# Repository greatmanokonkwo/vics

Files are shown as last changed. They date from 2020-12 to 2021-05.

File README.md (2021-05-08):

# V.I.C.S (Visual Impairment Companion System)
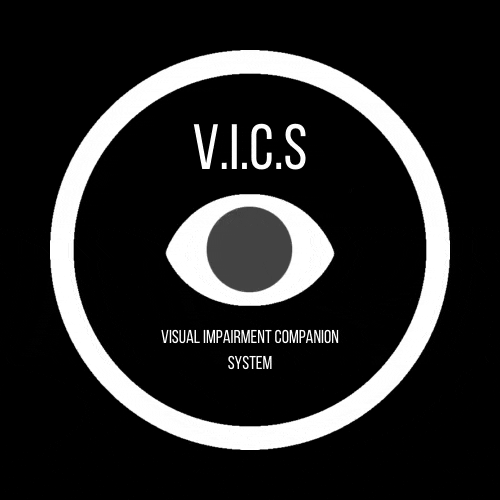
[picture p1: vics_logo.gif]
VICS LOGO

 
**Powered by Nvidia**

VICS is an end-to-end learning based visual impairment device that strives to make the world more accessible to the visually impaired. VICS is currently made up of three separate systems that work to bring the world to the user via a suite of information rallying devices including vibration motors and speech enabled assistance.

## Running on native machine
### Hardware Configuration
```
sudo /opt/nvidia/jetson-io/jetson-io.py (Configure mic hardware first then configure i2s4 pins)
sudo grep dap4 /sys/kernel/debug/tegra_pinctrl_reg
alsactl init tegrasndt210ref
amixer -c tegrasndt210ref cset name="MVC1 Mux" I2S4
amixer -c tegrasndt210ref cset name="ADMAIF1 Mux" MVC1
amixer -c tegrasndt210ref cset name="MVC1 Vol" 13500
amixer -c tegrasndt210ref cset name='I2S4 codec bit format' 32
amixer -c tegrasndt210ref sget "MVC1 Channels"
````

### Pytorch prerequisites
```
sudo apt-get install -y --no-install-recommends python3-pip python3-dev libopenblas-dev libopenmpi2 openmpi-bin openmpi-common gfortran && sudo rm -rf /var/lib/apt/lists/*
pip3 install setuptools Cython wheel
pip3 install numpy --verbose
```
### Pytorch for Jetson nano

*Instructions from https://forums.developer.nvidia.com/t/pytorch-for-jetson-version-1-7-0-now-available/72048*

Install PyTorch pip wheel v1.8.0

```
wget https://nvidia.box.com/shared/static/p57jwntv436lfrd78inwl7iml6p13fzh.whl -O torch-1.8.0-cp36-cp36m-linux_aarch64.whl
sudo apt-get install python3-pip libopenblas-base libopenmpi-dev 
pip3 install Cython
pip3 install numpy torch-1.8.0-cp36-cp36m-linux_aarch64.whl
```
Install torchvision
```
sudo apt-get install libjpeg-dev zlib1g-dev libpython3-dev libavcodec-dev libavformat-dev libswscale-dev
git clone --branch v0.9.0 https://github.com/pytorch/vision torchvision   # see below for version of torchvision to download
cd torchvision
export BUILD_VERSION=0.9.0
sudo python3 setup.py install    
cd ../ 
```
Install torchaudio
```
sudo apt-get update 
sudo apt-get install sox libsox-dev libsox-fmt-all
git clone -b v0.8.0 https://github.com/pytorch/audio torchaudio
cd torchaudio
export BUILD_VERSION=0.8.0
sudo python3 setup.py install
```

### pip install packages
```
sudo apt-get install portaudio19-dev
pip3 install --user --upgrade -r requirements.txt
```

### Google Cloud Text-to-Speech API key

```
wget https://dl.google.com/dl/cloudsdk/channels/rapid/downloads/google-cloud-sdk-329.0.0-linux-x86_64.tar.gz
tar -xvzf google-cloud-sdk-329.0.0-linux-x86_64.tar.gz
./google-cloud-sdk/install.sh
(Select mystical-ace-305717 project)
./google-cloud-sdk/bin/gcloud init
source ~/.bashrc
gcloud auth list
gcloud config list project
gcloud services enable texttospeech.googleapis.com
export PROJECT_ID=$(gcloud config get-value core/project)
echo "export PROJECT_ID=$(gcloud config get-value core/project)" > ~/.bashrc
gcloud iam service-accounts keys create ~/key.json --iam-account my-tts-sa@${PROJECT_ID}.iam.gserviceaccount.com
export GOOGLE_APPLICATION_CREDENTIALS=~/key.json
echo export GOOGLE_APPLICATION_CREDENTIALS=~/key.json > ~/.bashrc
```

### Google Tesseract-OCR Engine
```
sudo apt get install tesseract-ocr
sudo apt-get install libjpeg8 libjpeg62-dev libfreetype6 libfreetype6-dev
wget https://github.com/ZER-0-NE/EAST-Detector-for-text-detection-using-OpenCV/blob/master/frozen_east_text_detection.pb
```

### YOLOV3 weights file

Download the weights file in ``vics/speech_and_comms/scene_describe_system/weights``

```
wget https://pjreddie.com/media/files/yolov3-tiny.weights
```
## TO-DO 
**NOTE:** All tasks involving the GPS Guidance System should be held off until everything else has been completed. This is only an extension of the project.

### General Hardware

- [x] Jetson Nano Developer Kit 4-GB
- [ ] Design rechargeable battery / buy a rechargeable battery

### 1. Direction Planning System

#### Software 

- [x] Implement AlexNet architecture for Direction Planning (direction_plan/neuralnet/model.py) 
- [x] Write training process for the Direction Planning System (direction_plan/neuralnet/train.py)
- [x] Interface vibration motor for halt signalling (direction_plan/devices/vibrator_motor.py)
- [x] Finish up mpu6050 code to enable calculation of Yaw angle (direction_plan/devices/mpu6050.py)
- [x] Figure out halt signal calculations (direction_plan/collect_data.py)
- [x] Build direction_plan interfacing engine (direction_plan/engine.py)
- [ ] Collect data (data such as stopping at cross walks and roads be very helpful)

#### Hardware

- [x] MPU9250 9-axis IMU sensor
- [x] Raspberry Pi Camerasudo apt-get install libjpeg8 libjpeg62-dev libfreetype6 libfreetype6-dev
- [x] 2x Vibration motors
- [x] Get and setup Macro/Wide lens for Pi Camera

### 2. Speech and Communications Systems (Voice Assistant and Scene Description)

#### Sofware

- [x] Interface with microphone hardware
- [x] Interface with speaker hardware
- [x] Write object detection model 
- [x] Build WakeWord model for AI voice assistant (wake word: "Hey VICS")
- [x] Build NLP model for taking in audio input and return a classification for the command issued
- [x] Using the detected objects find way to create voice responses with the detected objects
- [x] Write data collection scripts

#### Hardware

- [x] SPH0645LM4H MEMS Microphone
- [x] MAX98357A Amflifier

### Product Design

#### Software

- [x] Design CAD for Enclosure using FreeCAD

#### Hardware

- [x] Create chest mount straps
- [x] 3d print Enclosure

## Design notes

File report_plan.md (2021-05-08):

# VICS (Visual Impairment Companion System) Technical Report

## Introduction
- The challenges faced by visually impaired
- WHO fact
- Personal Motivation
- Objective of project

## Research & Investigations

### Navigation
- Initial considerations and wants
- Investigated methods and their advantages and disadvantages
- Current method in-depth description, advantages and disadavantages

### Object Detection
- Talk about YoloV3 detection accuracy and speed

### Reading
- Talk about EAST detection
- Talk about Tesseract OCR 

## Hardware System Overview
- Sensors and hardware, used and why
- Circuit Diagram

## Software System Architecture

### Navigation
- System implemenation (system design) (See fig. 2 of main paper)

### Figures
- Create software architecture figure (See fig. 2 of main paper)
- Create logic flowchart of software system

## Training
- Talk about how Yolo, east, & tesseract are pretrained modules
- Briefly explaining training to the layman
- Talk about hardware used for training

### Navigation 
- Talk about data collection methods, as well as some of the data collected
- Talk about loss functions, training accuracies
- Show graph of training

### Wakeword module
- Talk about data collection methods and technques
- Talk about model accuracies
- Show graph for training

### Commands module
- Talk about data collection methods and techniques
- Talk about model accuracies
- Show graph for training

## Results

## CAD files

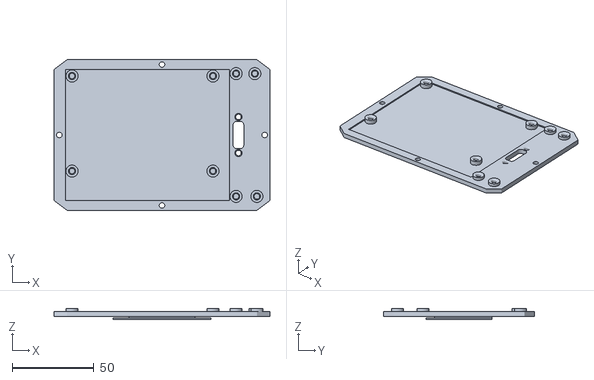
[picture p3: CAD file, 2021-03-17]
hardware/vics_bottom.stl
131.8 x 92.0 x 7.00

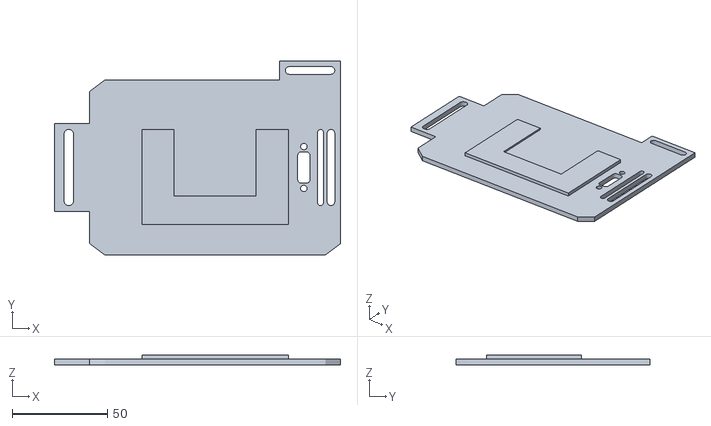
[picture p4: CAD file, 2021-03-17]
hardware/chest_mount.stl
150.3 x 102.0 x 5.00

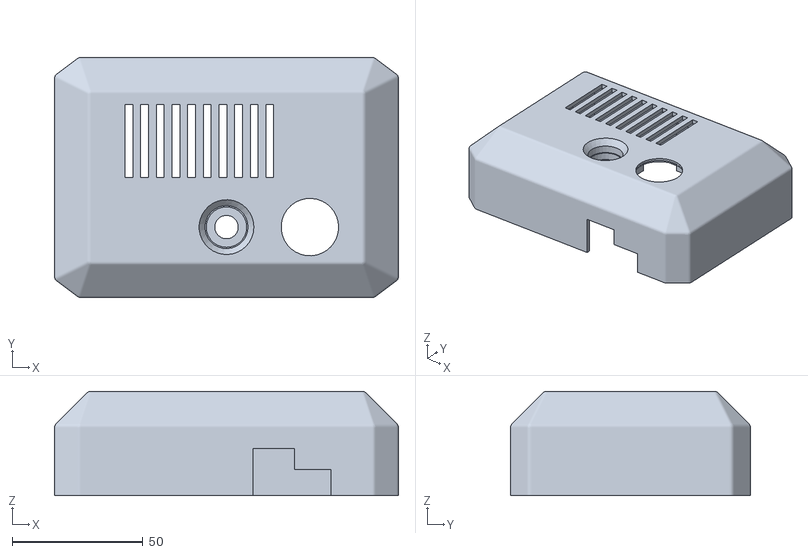
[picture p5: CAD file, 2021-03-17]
hardware/vics_top.stl
131.8 x 92.0 x 40.0

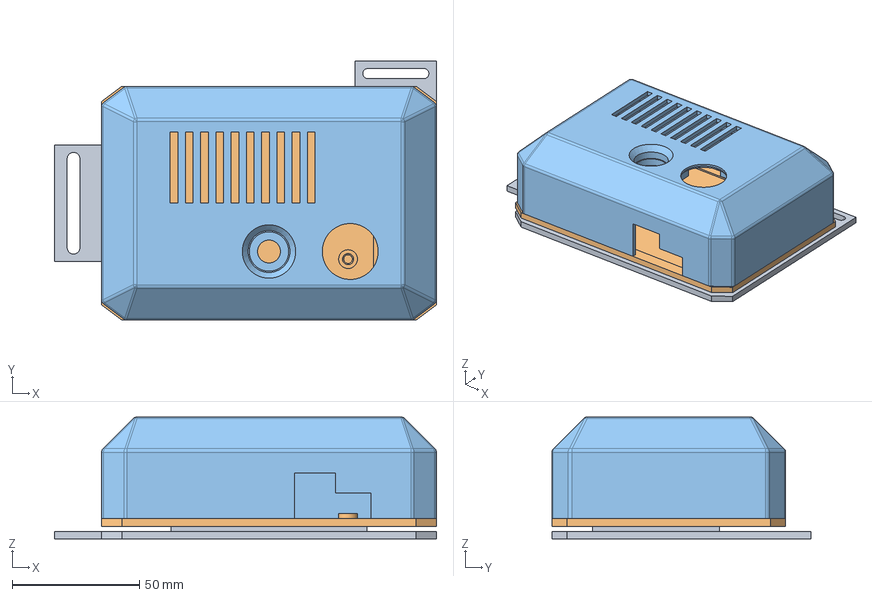
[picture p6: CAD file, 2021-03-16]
hardware/VICS_PARTS_CAD.FCStd
150.3 x 102.0 x 48.0 mm
Chest Mount
Bottom
Top

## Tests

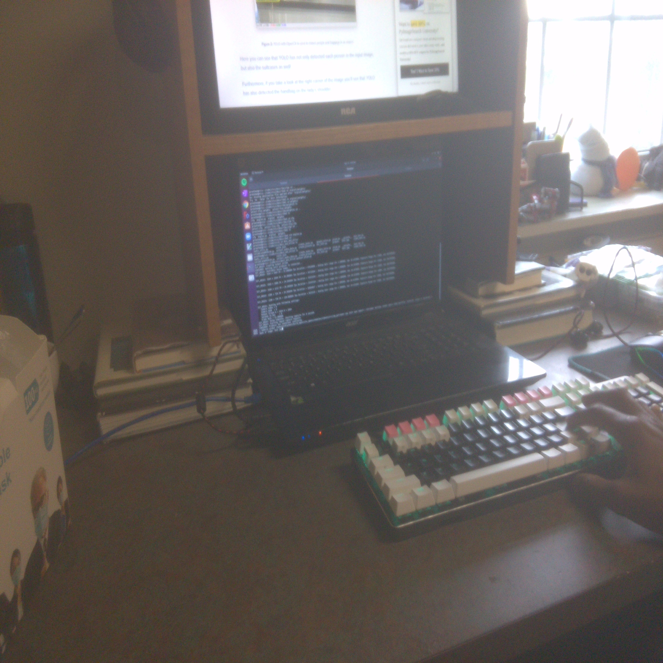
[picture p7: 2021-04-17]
describe/imgs/test.jpg

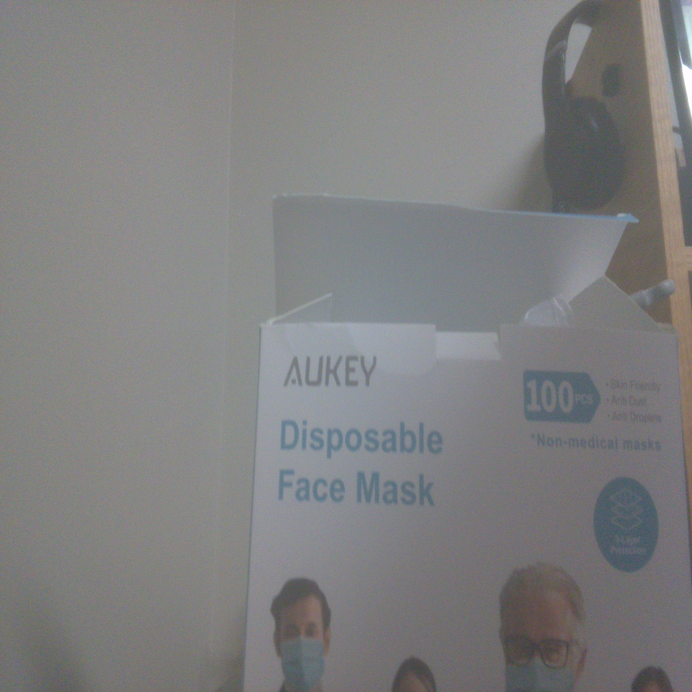
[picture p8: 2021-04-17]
read/test.jpg

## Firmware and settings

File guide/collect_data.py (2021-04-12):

"""
BEFORE RUNNING DATA_COLLECTION SCRIPT MAKE SURE THE MPU9250 HAS BEEN PROPERLY CALIBERATED AND PRODUCEDS ACCURATE YAW VALUES

SPEED CONSIDERATIONS:
- Walk at an average pace of 0.5 m/s or anything around there. 
- If you need to walker faster/slower then you would need to change to update time of the collector
- The collector runs at an update time of approx 1 second (collects image and direction pairs)
- Modify the UPDATE_TIME constant just on the top of the file. The wearter can test out direction UPDATE_TIME values for optimal usage

ROTATIONS:
- Rotations are calculated as the maximum displacement angle within the UPDATE_TIME span
- That being said the wearer should be certain of the direction they want to go. Make dilberate turns
- DON'T TURN MORE THAN 90 DEGREES IN EACH DIRECTION! The system only considers angles within [-101.25, 101.25] degrees (202.25 degrees) 
- Rotations should also be done in the window of the update time 

STOPPING:
- The stopping detector works by keep track of the bouncing motion on the z-axis. 
- Since while walking the user moves up and down and algorithm knows the user has stopped walking when the up and down motion stops
- The up and down motion is detected using the accelerometer sensors z-axis
- At rest the value of the accelerometer's z-axis is -9.8 meters, representing the acceleration due to gravity
- The algorithm calculates the accelerometer values over the spand of UPDATE_TIME and saves the maximum value over that interval
- Then, if the difference betwee n the maximum acceleration value and the rest value is greater than some threshold value THRESH, it is concluding that user is walking
- The value of THRESH can be tweaked to match the walking style of the user.

TESTING:
- For testing the angle, halt and final direction class values are printed out to the standard output
- Looking at these values can help tweak some of the values like UPDATE_TIME and THRESH
- For more testing on the mpu9250 yaw estimation and halt detection, go to ../devices/test_mpu.py

STOPPING CONDITIONS:
- Stop when a human being is in front of you
- Stop in front of a crosswalk
- Stop when there is a closed door in front of you in a closed room, open in the door and continue. Whiling opeing door, try not to make a lot of movements
- Stop when stairs have been encountered. Try to get top and bottom views of stairs in data. Same goes for escalators if any encountered. Highly doubt though

WHAT TO DO:
- Walk down multiple routes like you would normally do
- Try to capture edge cases such as environments with glass doors, stairs, and crosswalks from direction viewing angles, while walking
""" 

import os
os.sys.path.append("..")

import cv2
import time
import smbus

from imusensor.MPU9250 import MPU9250
from imusensor.filters import madgwick

from devs_and_utils.picam import picam 

# UPDATE TIMER VARAIBLE
UPDATE_TIME = 2.8
MIDLINE = -9.8
THRESH = 0.6

# MPU9250 IMU sensor and sensorfusion algorithm
sensorfusion = madgwick.Madgwick()
imu = None 

# Raspberry Pi Camera V2
cam = None 

capture_type = None # The script can either collect image data from live camera feed or prerecorded and saved video data

initial_yaw = 0

def initialize_devices(width=256, height=256):
	global imu

	if capture_type == "live":
		global cam 
		cam = picam(width, height)
	
	# Initialize MPU-6050 device
	address = 0x68
	bus = smbus.SMBus(1)
	imu = MPU9250.MPU9250(bus, address)
	imu.begin()
	
	calib_file = "../devs_and_utils/calib.json" # path of caliberation file with caliberated values

	if os.path.exists(calib_file):	
		imu.loadCalibDataFromFile(calib_file)
	else:
		print("Unable to find IMU caliberation file")

# Classify a given angle in degrees as one of the 9 direction classes
# [-PI/2, -3PI/8, -PI/4, -PI/8, 0, PI/8, PI/4, 3PI/8, PI/2]
def get_direction_class(angle):
	if (angle < -67.5) & (angle >= -112.5):
		return 0
	elif (angle < -22.5) & (angle >= -67.5):
		return 1
	elif (angle < 22.5) & (angle >= -22.5):
		return 2
	elif (angle < 67.5) & (angle >= 22.5):
		return 3
	elif (angle < 112.5) & (angle >= 67.5):
		return 4
	else:
		return -1
		
def calculate_yaw(currTime):
	
	# Calculate the change in the yaw angle of the mpu9250 device
	for i in range(10):
		newTime = time.time()
		dt = newTime - currTime
		currTime = newTime

		sensorfusion.updateRollPitchYaw(imu.AccelVals[0], imu.AccelVals[1], imu.AccelVals[2], imu.GyroVals[0], imu.GyroVals[1], imu.GyroVals[2], imu.MagVals[0], imu.MagVals[1], imu.MagVals[2], dt)
	
	return currTime

# Data collection process	
def data_collection(mins, path, fps, sample):
	global prevTime_yaw, prevTime_vel

	# Creating a VideoCapture object to read the video
	cap = cv2.VideoCapture(sample)

	# Get the ID of the last processed data sample
	with open(path+"/last.txt") as f:
		count = int(f.read())

	START_TIME = time.time()	

	img = None

	# Yaw calculation variables
	prev_yaw = 0
	direct_class = None
	max_angle = 0
	initial_yaw = 0

	# Halt classification variables
	## Halting is classified by using the principle that when people walk they oscillate up and down. Given the acceleration in the z-axis we can thus determine if the user is walking by calculating the amplitude value at a given interval. If the amplitude is below a certain threshold that means the user is not walking
	midline = -9.8
	thresh = 0.6
	max_accel = -999	

	currTime = time.time()

	# Loop until specified minutes have elasped

	if capture_type == "live":
		
		interval_start = START_TIME
		new_interval = True

		while time.time() - START_TIME < mins*60:

			imu.readSensor()
			currTime = calculate_yaw(currTime)

			newTime = time.time()

			# The sensor fusion algorithm spends the first few seconds of calculations slightly off. In order not the take this off values as are starting values we retake the initial_yaw for the first five seconds
			if newTime - START_TIME < 12.5:
				initial_yaw = sensorfusion.yaw
				interval_start = newTime
				continue
			
			# Take a frame from each second of the video
			if new_interval:
				new_interval = False
				img = cam.capture_image()
				
			# Calculate maximum accelorometer value on the z-axis
			max_accel = max(imu.AccelVals[2], max_accel)

			yaw_angle = -(sensorfusion.yaw - initial_yaw) # The magnetometer measures heading from the earth's true north, we need to set the user's initial heading as the reference point
			angle = int(yaw_angle - prev_yaw) # The displacement angle is the (yaw angle) - (previous yaw angle)

			if abs(angle) > abs(max_angle):
				max_angle = angle
				
			# Save he image as well as the motion in format direct_class/id_angle.jpg
			if newTime - interval_start >= UPDATE_TIME:

				halt = 0
				if (max_accel - MIDLINE) < THRESH:
					direct_class = 5 # Halt was detected
					halt = 1
				else:
					direct_class = get_direction_class(max_angle)

				if direct_class != -1:
					# Save image and direction pair
					cam.save_image(path=(path+"/"+str(direct_class)+"/"+str(count)+"_"+str(max_angle)+".jpg"), img=img)
								
					# Test out the angle, stop and direction class values. For max_accel if you are walking it should be 0 and if you stop it should be 1
					print(max_angle, halt, direct_class, yaw_angle, prev_yaw)
				else:
					print("Invalid movement direction")

				max_angle = 0
				max_halt = 0
				prev_yaw = -(sensorfusion.yaw - initial_yaw)
	
				max_accel = -999
			
				interval_start = time.time()
				new_interval = True

				count+=1

	else:	
	
		fps_counter = 0

		while (cap.isOpened()):

			imu.readSensor()
			currTime = calculate_yaw(currTime)

			# The sensor fusion algorithm spends the first few seconds of calculations slightly off. In order not the take this off values as are starting values we retake the initial_yaw for the first five seconds
			if time.time() - START_TIME < 12.5:
				initial_yaw = sensorfusion.yaw
				continue

			# Collect a frame each time in the loop	
			ret, frame = cap.read()
			cv2.imshow("Video", frame)
		
			# Calculate maximum accelorometer value on the z-axis
			max_accel = max(imu.AccelVals[2], max_accel)

			yaw_angle = -(sensorfusion.yaw - initial_yaw) # The magnetometer measures heading from the earth's true north, we need to set the user's initial heading as the reference point
			angle = int(yaw_angle - prev_yaw) # The displacement angle is the (yaw angle) - (previous yaw angle)

			if abs(angle) > abs(max_angle):
				max_angle = angle
				
			# Save he image as well as the motion in format direct_class/id_angle.jpg
			if fps_counter >= fps:
				fps_counter = 0
				img = cv2.resize(frame, (416, 416), fx=0, fy=0, interpolation = cv2.INTER_CUBIC)

				halt = 0
				if (max_accel - MIDLINE) < THRESH:
					direct_class = 9 # Halt was detected
					halt = 1
				else:
					direct_class = get_direction_class(max_angle)

				if direct_class != -1:
					# Save image and direction pair
					cv2.imwrite((path+"/"+str(direct_class)+"/"+str(count)+"_"+str(max_angle)+".jpg"), img)
								
					# Test out the angle, stop and direction class values. For max_accel if you are walking it should be 0 and if you stop it should be 1
					print(max_angle, halt, direct_class)
				else:
					print("Invalid movement direction")

				max_angle = 0
				max_halt = 0
				prev_yaw = -(sensorfusion.yaw - initial_yaw)
	
				max_accel = -999
			
				count+=1

	# Update the start.txt file with ID of lastest processed data sample
	with open(path+"/last.txt", "w") as f:
		f.write(str(count))

if __name__=="__main__":
	data_path = str(input("Where should the dataset be stored (The path should contain a last.txt file and an images directory): "))
	capture_type = str(input("Is the data coming from a live camera feed or a prerecorded video? (live or video): ")).lower()

	mins = None
	fps = None
	video_sample = None

	if capture_type == "live":
		mins = float(input("How long should the collection script run (in mins): "))
	else:
		video_sample = str(input("Path of your video data sample: "))
		fps = int(input("What is the fps of the video? "))
	
	initialize_devices()

	print ("Get set up. Data collection will start in 30 seconds.")
	# Give time handle any setups to get collector ready to start taking in data
	# time.sleep(30)
	# Change the minutes to the how long you want to run the program for 
	data_collection(mins=mins, path=data_path, fps=fps, sample=video_sample)

	if capture_type == "live":
		cam.cleanup()

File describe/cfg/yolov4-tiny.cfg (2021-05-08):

[net]
# Testing
#batch=1
#subdivisions=1
# Training
batch=64
subdivisions=1
width=416
height=416
channels=3
momentum=0.9
decay=0.0005
angle=0
saturation = 1.5
exposure = 1.5
hue=.1

learning_rate=0.00261
burn_in=1000

max_batches = 2000200
policy=steps
steps=1600000,1800000
scales=.1,.1


#weights_reject_freq=1001
#ema_alpha=0.9998
#equidistant_point=1000
#num_sigmas_reject_badlabels=3
#badlabels_rejection_percentage=0.2


[convolutional]
batch_normalize=1
filters=32
size=3
stride=2
pad=1
activation=leaky

[convolutional]
batch_normalize=1
filters=64
size=3
stride=2
pad=1
activation=leaky

[convolutional]
batch_normalize=1
filters=64
size=3
stride=1
pad=1
activation=leaky

[route]
layers=-1
groups=2
group_id=1

[convolutional]
batch_normalize=1
filters=32
size=3
stride=1
pad=1
activation=leaky

[convolutional]
batch_normalize=1
filters=32
size=3
stride=1
pad=1
activation=leaky

[route]
layers = -1,-2

[convolutional]
batch_normalize=1
filters=64
size=1
stride=1
pad=1
activation=leaky

[route]
layers = -6,-1

[maxpool]
size=2
stride=2

[convolutional]
batch_normalize=1
filters=128
size=3
stride=1
pad=1
activation=leaky

[route]
layers=-1
groups=2
group_id=1

[convolutional]
batch_normalize=1
filters=64
size=3
stride=1
pad=1
activation=leaky

[convolutional]
batch_normalize=1
filters=64
size=3
stride=1
pad=1
activation=leaky

[route]
layers = -1,-2

[convolutional]
batch_normalize=1
filters=128
size=1
stride=1
pad=1
activation=leaky

[route]
layers = -6,-1

[maxpool]
size=2
stride=2

[convolutional]
batch_normalize=1
filters=256
size=3
stride=1
pad=1
activation=leaky

[route]
layers=-1
groups=2
group_id=1

[convolutional]
batch_normalize=1
filters=128
size=3
stride=1
pad=1
activation=leaky

[convolutional]
batch_normalize=1
filters=128
size=3
stride=1
pad=1
activation=leaky

[route]
layers = -1,-2

[convolutional]
batch_normalize=1
filters=256
size=1
stride=1
pad=1
activation=leaky

[route]
layers = -6,-1

[maxpool]
size=2
stride=2

[convolutional]
batch_normalize=1
filters=512
size=3
stride=1
pad=1
activation=leaky

##################################

[convolutional]
batch_normalize=1
filters=256
size=1
stride=1
pad=1
activation=leaky

[convolutional]
batch_normalize=1
filters=512
size=3
stride=1
pad=1
activation=leaky

[convolutional]
size=1
stride=1
pad=1
filters=255
activation=linear



[yolo]
mask = 3,4,5
anchors = 10,14,  23,27,  37,58,  81,82,  135,169,  344,319
classes=80
num=6
jitter=.3
scale_x_y = 1.05
cls_normalizer=1.0
iou_normalizer=0.07
iou_loss=ciou
ignore_thresh = .7
truth_thresh = 1
random=0
resize=1.5
nms_kind=greedynms
beta_nms=0.6
#new_coords=1
#scale_x_y = 2.0

[route]
layers = -4

[convolutional]
batch_normalize=1
filters=128
size=1
stride=1
pad=1
activation=leaky

[upsample]
stride=2

[route]
layers = -1, 23

[convolutional]
batch_normalize=1
filters=256
size=3
stride=1
pad=1
activation=leaky

[convolutional]
size=1
stride=1
pad=1
filters=255
activation=linear

[yolo]
mask = 1,2,3
anchors = 10,14,  23,27,  37,58,  81,82,  135,169,  344,319
classes=80
num=6
jitter=.3
scale_x_y = 1.05
cls_normalizer=1.0
iou_normalizer=0.07
iou_loss=ciou
ignore_thresh = .7
truth_thresh = 1
random=0
resize=1.5
nms_kind=greedynms
beta_nms=0.6
#new_coords=1
#scale_x_y = 2.0

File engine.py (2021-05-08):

import os
import time
import threading
import playsound
<<<<<<< HEAD
#import Jetson.GPIO as GPIO
=======
import Jetson.GPIO as GPIO
>>>>>>> 40c4c125e3f3837dbdf28e6be73a6f1a5c234e21
import pyaudio
import wave

import torch
import torchaudio

<<<<<<< HEAD
import wakeword.engine
from wakeword import neuralnet
import command_processor
import guide 
import describe  
import read 

from devs_and_utils.picam import picam
from devs_and_utils.audio_utils import get_featurizer
from devs_and_utils.google_voice import GoogleVoice
=======
from wakeword.engine import WakeWordEngine, DemoAction
from command_processor.engine import LSTMCommands
from guide.engine import GuideSystem
from describe.engine import SceneDescribeSystem 
from read.engine import ReadingSystem

from devs_and_utils.picam import picam
from devs_and_utils.audio_utils import get_featurizer
>>>>>>> 40c4c125e3f3837dbdf28e6be73a6f1a5c234e21

"""
COMMAND 0 (Guide): This enable to GuideNet process that relays angles of direction to travel in to the user, using vibrations
COMMAND 1 (Describe): This enables the Scene description process, that detects various objects in front of the user and using voice, tells what these objects are and where they are located (left, center, right) relative to them
COMMAND 2 (Read): This enables to reading process which takes a picture of whatever is in front of the VICS gear camera and reads the text in the image
"""
# Global Variables

WAKEWORD_DETECTED = False
device = "cuda" if torch.cuda.is_available() else "cpu"

# General tools and devices 
cam = picam(width=1028, height=1028)

voice = GoogleVoice()
voice_name = "en-GB-Standard-B"

audio_transform = get_featurizer(8000)

# System Modules
## Wakeword
wakeword_engine = WakeWordEngine()

## Commands Detector
command_names = ["Guide Me", "Describe the Scene", "Read this"]

model_params = {
	"num_classes": 3, "feature_size": 40, "hidden_size": 128,
	"num_layers": 1, "dropout": 0.1, "bidirectional": False
}
<<<<<<< HEAD
commands_model = command_processor.engine.LSTMCommands(**model_params, device=device)
=======
commands_model = LSTMCommands(**model_params, device=device)
>>>>>>> 40c4c125e3f3837dbdf28e6be73a6f1a5c234e21
params_path = "commands_processor/neuralnet/commands.pt"

commands_model.load_state_dict(torch.load(params_path)["model_state_dict"])
commands_model = model.to(device)

audio_transform = get_featurizer(8000)

## Guidance System
<<<<<<< HEAD
guide = GuideSystem()
=======
guide = GuideSystem
>>>>>>> 40c4c125e3f3837dbdf28e6be73a6f1a5c234e21

## Scene Description System
describe = SceneDescribeSystem()

## Reading system
read = ReadingSytem()

# Module Functions

## WakeWord 
def wakeword_action(prediction):
	if prediction == 1:
		WAKEWORD_DETECTED = True
		playsound("devs_and_utils/presets/greet.wav")
		command = threading.Thread(target=commands_run, args=())
		print("Starting Command Sequence ...")
		WAKEWORD_DETECTED = False
		command.start()
	
## Commands Detector
def record_audio(seconds=5):
	chunk = 1024
	sample_format = pyaudio.paInt16
	channels = 1
	fs = 8000
	filename = "voice_command.wav"
	
	p = pyaudio.PyAudio()
	
	print("Recording")
	
	stream = p.open(format=sample_format,
					channels=channels,
					rate=fs,
					frames_per_buffer=chunk,
					input=True)
		
	frames = []
	
	for i in range(0, int(fs/chunk * seconds)):
		data = stream.read(chunk)
		frames.append(data)
	
	stream.stop_stream()
	stream.close()
		
	p.terminate()
	
	print("Finished recording")
	
	wf = wave.open(filename, "wb")
	wf.setnchannels(channels)
	wf.setsampwidth(p.get_sample_size(sample_format))
	wf.setframerate(fs)
	wf.writeframes(b''.join(frames))
	wf.close()

def open_and_transform_audio():
	# Transform the recorded audio for inference by commands detection model
	waveform, sr = torchaudio.load("voice_command.wav")
	os.remove("voice_command.wav")
	mfcc = audio_transform(waveform).transpose(1, 2).transpose(0, 1)
	mfcc = mfcc.to(device)	

	return mfcc

def commands_run():
	global WAKEWORD_DETECTED # Main thread will change this signal if the wakeword is detected, prompting function to stop executing

	# Record Audio for voice command
	record_audio()
	start_t = time.time()
	output = commands_model(open_and_transform_audio())[0]

	_, pred = torch.max(torch.sigmoid(output), dim=1)
	print(f"[INFO] Detected \"{commands_names[pred]}\" command in {start_t - time.time()} seconds!")

	if pred == 0:
		# Play preset response
		playsound("devs_and_utils/presets/guide.wav")

		while WAKEWORD_DETECTED == False:
			guide.run(cam)
			
	else:
		if pred == 1:
			playsound("devs_and_utils/presets/describe.wav")
<<<<<<< HEAD
		elif pred == 2:
=======
		else pred == 2:
>>>>>>> 40c4c125e3f3837dbdf28e6be73a6f1a5c234e21
			playsound("devs_and_utils/presets/read.wav")

		start_t = time.time()

		if pred == 1:
			response = describe.run(cam=cam)
			print("[INFO] Scene Description detected objects in {start_t - time.time()} seconds!")
<<<<<<< HEAD
		elif pred == 2:
=======
		else if pred == 2:
>>>>>>> 40c4c125e3f3837dbdf28e6be73a6f1a5c234e21
			response = read.run(cam=cam)
			print("[INFO] eading completed in {start_t - time.time()} seconds!")

		voice.text_to_speech(voice_name=voice_name, text=response, name="response") # Turn generated response to speech
		playsound("response.wav") # play response on speakers
		os.remove("response.wav") # Delete generate response file


if __name__ == "__main__":
	print("Settting up device ... this should take a few seconds")
	read.run()

	action = wakeword_action() # This action is called by the wakeword whenever it makes a prediction. It activates the command detection and run sequence
	wakeword_engine.run(action)	
	threading.Event().wait()

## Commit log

2020-12-17 Changed IMU interface from local version to the library version
2021-01-03 Update device locations
2021-01-03 Switched to direction class inference and calculations
2021-01-03 Renamed tools_and_devices directory to sensors_and_tools
2021-01-10 Completed VICS scene description system
    [yolov3.cfg]
2021-01-10 Renamed modules for simplicity
    [yolov3.cfg]
2021-01-10 Fixed GoogleVoice API code
    [google_voice.py]
2021-01-14 Wrote test script for imu library
2021-01-16 Added a description of the VICS device to README.md
2021-01-23 Fixed darknet.py issue of not running on GPU
    [engine.py]
2021-01-23 Fixed guide/engine.py and other bugs
    [caliberateMPU9250.py, collect_data.py, engine.py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]
2021-01-25 Added yolov4-tiny.cfg configuration file, yolov3.cfg is too large and slow
    [yolov4-tiny.cfg]
2021-02-01 Edited collect_data.py
    [yolov3-tiny.cfg, yolov3.cfg]
2021-02-11 darknet yolov3-tiny replaced yolov3, for faster inference
    [yolov3.cfg]
2021-03-11 Adding CAD files for eletronics enclosure in hardware/
    [VICS_TOP.FCStd]
2021-03-14 Updated CAD file designs
    [Lens.FCStd, VICS_TOP.FCStd, vics_bottom.step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]
2021-03-14 Finished modelling vics electronics enclosure CAD files
2021-03-16 Added chest mount CAD file
    [VICS_BOTTOM.FCStd, VICS_PARTS_CAD.FCStd, VICS_TOP.FCStd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]
2021-03-16 Added export .stp files for each part to be printed
    [chest_mount.step, vics_bottom.step, vics_top.step]
2021-03-17 Arranged hardware/ directory to only *.stl files and .FCStd file for all parts
    [Lens.FCStd, chest_mount.step, chest_mount.stl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]
2021-03-17 Added audio collection script
    [VICS_PARTS_CAD.FCStd]
2021-04-12 Did a lot
    [yolov3.cfg]
2021-04-29 Edited dataset.py
    [yolov4-tiny.cfg, yolov4.cfg]
